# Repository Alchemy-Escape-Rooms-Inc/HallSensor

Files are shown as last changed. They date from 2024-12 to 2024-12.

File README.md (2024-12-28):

# Hall Sensor
Repository dedicated to Alchemy Escape Rooms digital hall sensor

# Folder Structure
## Assembly
Documentation on building

## BOM
.xlsx bom for all parts

## Design
Source code, source models, pcb projects, etc.

## Documentation
User and integration guides, etc.

## Exports
Compiled binaries, printable stl models, etc.

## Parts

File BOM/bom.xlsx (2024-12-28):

Part | Specs | Designation | Mfr Part # | Ordering Reference | Notes
PCB |  |  |  |  | Can be ordered from PCBWay using PCBWay plugin for KiCad, Open Design\PCB\DigitalHallSensor\Panelized\DigitalHallSensorPanelized\Output.kicad_pcb
ALS31300 | 500G Variant | U1 | ALS31300EEJASR-500 | https://www.mouser.com/ProductDetail/250-31300EEJASR500
Capacitor | X7R 0402 0.1uF | C1 | 04026C104KAT2A | https://www.mouser.com/ProductDetail/581-04026C104KAT2A
Header | JST PH 4 Pin Vertical Female Socket | J1, J2 |  | https://www.amazon.com/dp/B0731MZCGF

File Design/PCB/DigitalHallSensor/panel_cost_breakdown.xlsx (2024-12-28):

PanelCount | Total |  | pcb cost per | component cost | total cost per
16 | 80 | 68.55 | 0.171375 | 3 | 3.171375
9 | 45 | 51.03 | 0.2268 | 3 | 3.2268
25 | 125 | 85.8 | 0.13728 | 3 | 3.13728
4 | 20 | 24.88 | 0.2488 | 3 | 3.2488
 | 0 |  | #DIV/0! | 3 | #DIV/0!
 | 0 |  | #DIV/0! | 3 | #DIV/0!
 | 0 |  | #DIV/0! | 3 | #DIV/0!
 | 0 |  | #DIV/0! | 3 | #DIV/0!
 | 0 |  | #DIV/0! | 3 | #DIV/0!
 | 0 |  | #DIV/0! | 3 | #DIV/0!
 | 0 |  | #DIV/0! | 3 | #DIV/0!
 | 0 |  | #DIV/0! | 3 | #DIV/0!

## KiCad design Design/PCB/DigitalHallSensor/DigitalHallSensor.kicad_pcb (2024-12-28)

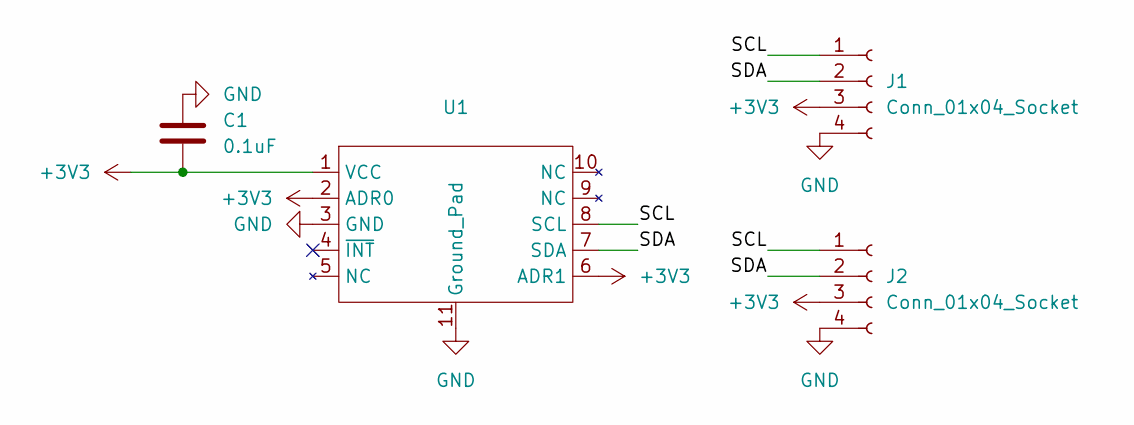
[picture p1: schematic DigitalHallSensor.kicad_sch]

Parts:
C1: 0.1uF; C_0402_1005Metric_Pad0.74x0.62mm_HandSolder
J1, J2: Conn_01x04_Socket; JST_PH_B4B-PH-K_1x04_P2.00mm_Vertical
U1: DFN-10-EJ

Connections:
+3V3: C1.2, J1.3, J2.3, U1.1 (VCC), U1.2 (ADR0), U1.6 (ADR1)
/SCL: J1.1, J2.1, U1.8 (SCL)
/SDA: J1.2, J2.2, U1.7 (SDA)
GND: C1.1, J1.4, J2.4, U1.3 (GND), U1.11 (Ground_Pad)

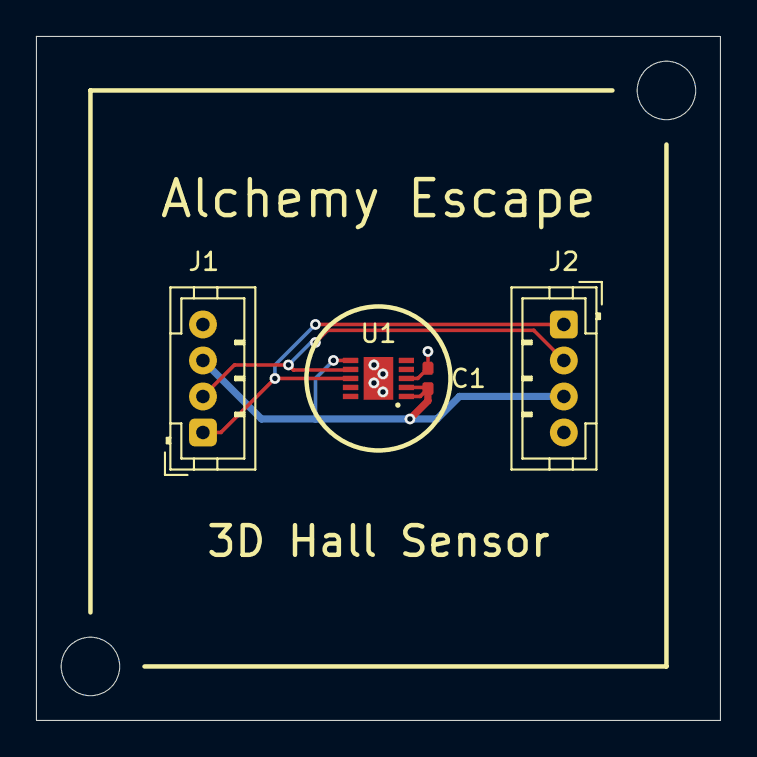
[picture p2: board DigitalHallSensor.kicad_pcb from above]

Board: 2 copper layers, 38.0 x 38.0 mm, 4 parts (0 on the bottom side), 4 nets.

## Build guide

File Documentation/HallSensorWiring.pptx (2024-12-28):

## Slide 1

BAC Wiring (No extenders up to one meter)

Use middle i2c header
And ensure VCCIO jumper is set to pins 2-3 (3.3V)

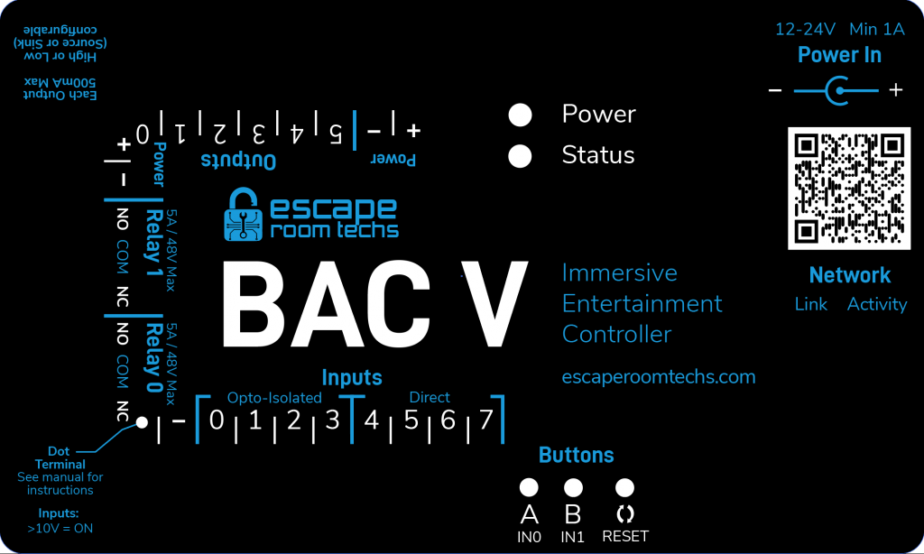
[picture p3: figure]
Escape Room Techs Staff – Escape Room Techs

FX45

I2C

Alchemy Escape
3D Hall Sensor

Alchemy Escape
3D Hall Sensor

Alchemy Escape
3D Hall Sensor

Alchemy Escape
3D Hall Sensor

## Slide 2

BAC Wiring (With extenders)

Use hi drive i2c header
And ensure VCCIO jumper is set to pins 1-2 (5V)

FX45

I2C

FX14-mini

Alchemy Escape
3D Hall Sensor

FX14-mini

FX14-mini

Alchemy Escape
3D Hall Sensor

Diagram incomplete, need hi drive -> ethernet wiring from ERT

Short JST cable

Long ethernet cable

JST Cable

Ethernet

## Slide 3

Microcontroller Wiring (No extenders up to one meter)

2.2K pullup resistor on SCL and SDA

3.3V+

GND

Cable pinout:
Pin 1: SCL
Pin 2: SDA
Pin 3: 3.3V+
Pin 4: Ground

SCL

SDA

Microcontroller

Pin 1 is square pad on hall sensor

Alchemy Escape
3D Hall Sensor

Alchemy Escape
3D Hall Sensor

Alchemy Escape
3D Hall Sensor

Alchemy Escape
3D Hall Sensor

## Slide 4

Microcontroller Wiring (With extenders)

2.2K pullup resistor on SCL and SDA

3.3V+

GND

Cable pinout:
Pin 1: SCL
Pin 2: SDA
Pin 3: 3.3V+
Pin 4: Ground

Microcontroller

SDA

SCL

Pin 1 is square pad on hall sensor

FX14-mini

FX14-mini

Alchemy Escape
3D Hall Sensor

FX14-mini

FX14-mini

Alchemy Escape
3D Hall Sensor

Long ethernet cable

Short JST cable

JST Cable

Ethernet

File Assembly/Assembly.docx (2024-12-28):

# Assembly

1. Tin all surface mount pads
2. Place U1 and hot air into place
3. Place C1 and hot air into place
4. Hand solder J1. The notch should face outward
5. Hand solder J2. The notch should face outward

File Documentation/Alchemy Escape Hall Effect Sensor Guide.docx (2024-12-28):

# Alchemy Escape Hall Effect Sensor

The alchemy escape hall effect sensor is capable of detecting magnet rotation as well as distance. It is based on the Allegro ALS31300 (https://www.allegromicro.com/-/media/files/datasheets/als31300-datasheet.ashx).

# Wiring

The sensors can be chained together using parallel 4 pin JST PH cables. The length of all cables should not exceed ~1 meter. See section on extending I2C for using the sensors at greater distances.

See HallSensorWiring.pdf for detailed wiring diagrams.

# Integration

### Rotational Detection Type

Magnets used for rotational detection need to be diametrically magnetized.

Here (https://www.kjmagnetics.com/proddetail.asp?prod=R834DIA) is a recommended magnet for rotational use.

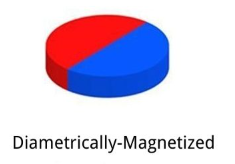
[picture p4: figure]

### Placement Detection Type

Magnets used for placement detection need to be axially magnetized.

The ½” x ½” N52 magnet here (https://shop.escaperoomtechs.com/products/magnets?variant=39931183431886) is a good choice for placement use.

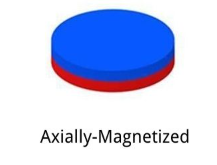
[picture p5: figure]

### Construction

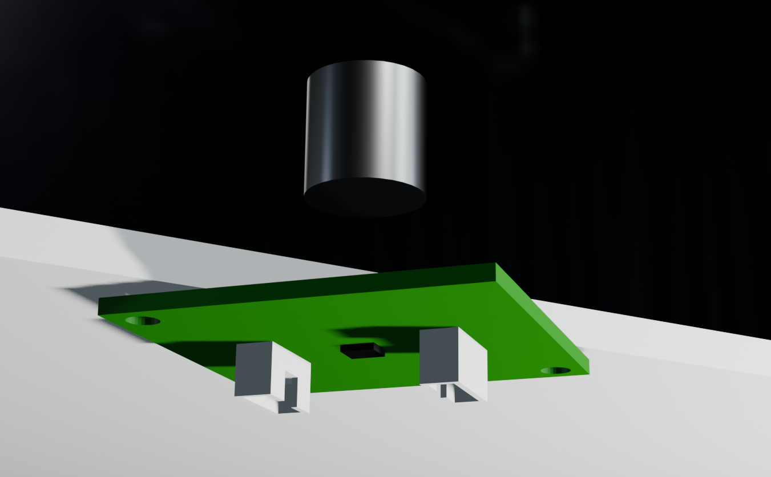
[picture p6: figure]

Sensor should be mounted to a flat surface on the underside. Magnet should be embedded in the prop or on a shaft depending on the detection type.

# Address Programming

Each sensor needs to be programmed with a unique address on the bus. By default, the sensors are programmed with address 0 from the factory. If there are 4 sensors on a bus, you may program them with addresses 1, 2, 3, and 4 for instance. I2C addresses range from 0-127.

BAC Compability Note: the BAC expects these sensors to have addresses 96-111

## Source

The source code (https://github.com/Alchemy-Escape-Rooms-Inc/HallSensor) runs on an ESP32-S3. By setting the old address and new address you can program the sensor. The program will attempt to set the device address on boot.

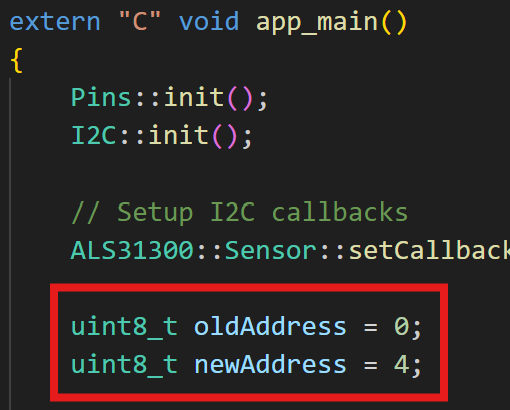
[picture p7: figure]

Here is the output of the example address programming above. First the device is programmed, and then after a power cycle it shows up at address 4.

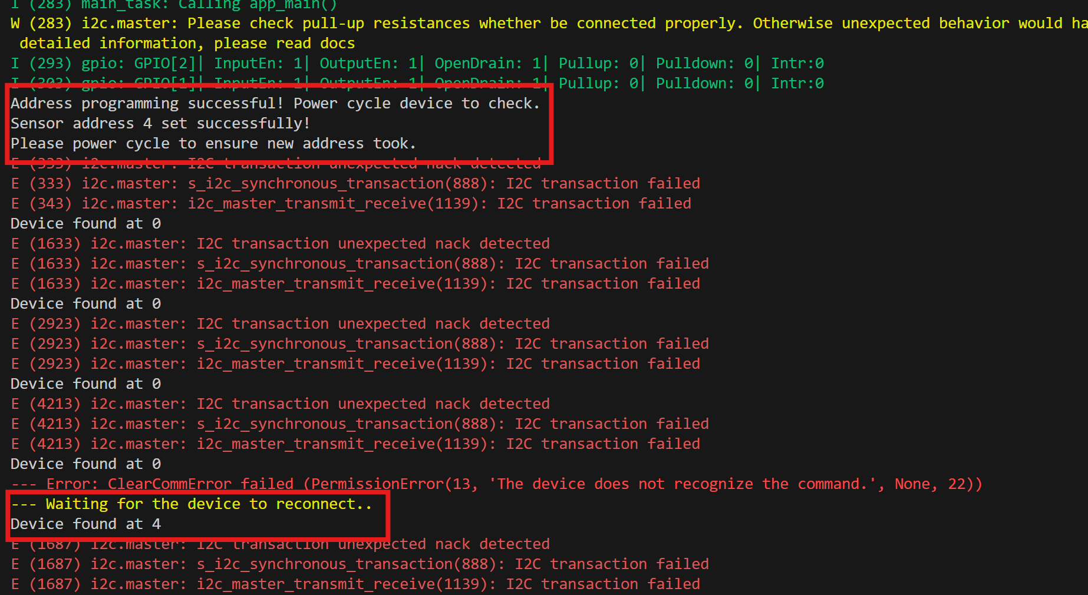
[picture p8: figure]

# Extending I2C

I2C has a max cable distance (end to end with all sensors) of roughly one meter. You can increase the distance by using lower value pullups / dropping transmission speed to get roughly double the distance. If the distances are much larger, you need to use an I2C extender. The FX14-mini (https://shop.escaperoomtechs.com/products/i2c-range-extender-fx14-mini) by Escape Room Techs can accomplish this.

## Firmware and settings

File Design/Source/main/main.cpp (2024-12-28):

#include "freertos/FreeRTOS.h"
#include "freertos/task.h"

#include "allegro/als31300.h"

#include "peripherals/i2c.h"
#include "peripherals/pins.h"

void i2cScan()
{
    // I2C Scanner
    for (int i = 0; i < 128; i++)
    {
        if (I2C::devicePresent(i))
        {
            printf("Device found at %i\n", i);
        }
        vTaskDelay(pdMS_TO_TICKS(10));
    }
}

void setAddress(uint8_t previousAddress, uint8_t newAddress)
{
    ALS31300::Sensor sensor(previousAddress);
    if (sensor.programAddress(newAddress)) printf("Sensor address %i set successfully!\n", newAddress);
    else printf("Sensor address %i failed!\n", newAddress);
}

void processSensor(ALS31300::Sensor& sensor)
{
    if (sensor.update())
    {
        printf("Sensor %i angle: %03d, Depth: %05d\n", sensor.address, sensor.getAngle(), (int) sensor.z);
    }
}

extern "C" void app_main()
{
    Pins::init();
    I2C::init();

    // Setup I2C callbacks
    ALS31300::Sensor::setCallbacks(I2C::registerDevice, I2C::unregisterDevice, I2C::changeAddress, I2C::write, I2C::read);

    uint8_t oldAddress = 0;
    uint8_t newAddress = 4;

    if (I2C::devicePresent(oldAddress))
    {
        // BAC Compatible addresses should be 96-111
        setAddress(oldAddress, newAddress);
        printf("Please power cycle to ensure new address took.\n"); // Power cycle after this
    }
    else
    {
        printf("Sensor address 0 not found, skipping programming!\n");
    }

    ALS31300::Sensor sensor1(1);
    ALS31300::Sensor sensor2(2);
    ALS31300::Sensor sensor3(3);
    ALS31300::Sensor sensor4(4);

    while (1)
    {
        processSensor(sensor1);
        processSensor(sensor2);
        processSensor(sensor3);
        processSensor(sensor4);

        i2cScan();
    }
}

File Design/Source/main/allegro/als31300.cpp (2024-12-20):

#include "als31300.h"
#include "registers.h"

#include <cstdio>
#include <cmath>

namespace ALS31300
{
    Sensor::ReadCallback Sensor::i2cRead = defaultReadCallback;
    Sensor::WriteCallback Sensor::i2cWrite = defaultWriteCallback;
    Sensor::RegisterCallback Sensor::i2cRegister = defaultRegisterCallback;
    Sensor::UnregisterCallback Sensor::i2cUnregister = defaultUnregisterCallback;
    Sensor::ChangeAddressCallback Sensor::i2cChangeAddress = defaultChangeAddressCallback;

    void Sensor::setCallbacks(RegisterCallback registerCallback, UnregisterCallback unregisterCallback, ChangeAddressCallback changeAddressCallback, WriteCallback writeCallback, ReadCallback readCallback)
    {
        i2cWrite = writeCallback;
        i2cRead = readCallback;
        i2cRegister = registerCallback;
        i2cUnregister = unregisterCallback;
        i2cChangeAddress = changeAddressCallback;
    }

    Sensor::Sensor(uint8_t address) : address(address & 0x7F)
    {
        i2cRegister(address);
    }

    Sensor::~Sensor()
    {
        i2cUnregister(address);
    }

    bool Sensor::update()
    {
        uint16_t newX, newY, newZ;

        uint32_t readData;
        if (!read(0x28, readData)) return false;
        Register0x28 reg28{readData};

        newX = reg28.xAxisMsbs << 8;
        newY = reg28.yAxisMsbs << 8;
        newZ = reg28.zAxisMsbs << 8;

        if (!read(0x29, readData)) return false;
        Register0x29 reg29{readData};

        newX |= reg29.xAxisLsbs;
        newY |= reg29.yAxisLsbs;
        newZ |= reg29.zAxisLsbs;

        const float filterIntensity = 32.0f;
        x = (float((int16_t) newX) + x * (filterIntensity - 1)) / filterIntensity;
        y = (float((int16_t) newY) + y * (filterIntensity - 1)) / filterIntensity;
        z = (float((int16_t) newZ) + z * (filterIntensity - 1)) / filterIntensity;

        return true;
    }

    bool Sensor::programAddress(uint8_t newAddress)
    {
        newAddress &= 0x7F;
        
        // Enter Customer Access Mode to enable register writes
        if (!write(customerAccessRegister, customerAccessCode)) return false;

        // Read register
        uint32_t readData;
        if (!read(0x02, readData)) return false;

        // Update address
        Register0x02 registerData = {readData};
        registerData.slaveAddress = newAddress;

        // Write new address
        if (!write(0x02, registerData.raw)) return false;

        printf("Address programming successful! Power cycle device to check.\n");
        
        return true;
    }

    bool Sensor::write(uint8_t reg, uint32_t value)
    {
        uint8_t sendPayload[5] =
        {
            reg,
            uint8_t(value >> 24 & 0xFF),
            uint8_t(value >> 16 & 0xFF),
            uint8_t(value >>  8 & 0xFF),
            uint8_t(value >>  0 & 0xFF)
        };

        return i2cWrite(address, sendPayload, 5);
    }

    bool Sensor::read(uint8_t reg, uint32_t& value)
    {
        uint8_t sendPayload = reg;
        uint8_t receivePayload[4];

        if (!i2cRead(address, &sendPayload, 1, receivePayload, 4)) return false;

        value = receivePayload[0] << 24 |
                receivePayload[1] << 16 |
                receivePayload[2] <<  8 |
                receivePayload[3];

        return true;
    }

    uint16_t Sensor::getAngle()
    {
        // TODO, normalize x and y to skip multiple conversions
        float currentAngle = angleFromXY(x, y);
        float currentX, currentY;
        xyFromAngle(currentAngle, currentX, currentY);

        float avgX, avgY;
        xyFromAngle(avgAngle, avgX, avgY);

        const float filterIntensity = 10.0f;
        avgX = (currentX + avgX * (filterIntensity - 1)) / filterIntensity;
        avgY = (currentY + avgY * (filterIntensity - 1)) / filterIntensity;

        avgAngle = angleFromXY(avgX, avgY);
        
        return avgAngle + 0.5f; // Round angle before casting to uint16_t
    }

    float Sensor::angleFromXY(float x, float y)
    {
        constexpr float PI = float(M_PI);
        constexpr float RAD_TO_DEG (180.0f / PI);

        float angle = atan2f(y, x) * RAD_TO_DEG;
        if (angle < 0) angle += 360.0f;
        
        return angle;
    }

    void Sensor::xyFromAngle(float angle, float& x, float& y)
    {
        constexpr float PI = float(M_PI);
        constexpr float DEG_TO_RAD (PI / 180.0f);

        x = cos(angle * DEG_TO_RAD);
        y = sin(angle * DEG_TO_RAD);
    }
}

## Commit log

2024-12-20 ESP32-S3 project containing integrated hall sensor library
    [partitions.csv]
2024-12-28 enabled i2c scanner, expanded reference to handle multiple sensors, made pin initialization function public
2024-12-28 Supporting documentation and PCB project
    [DigitalHallSensor.kicad_pcb, DigitalHallSensor.kicad_sch, DigitalHallSensorPanelized.kicad_pcb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]
2024-12-28 Added hall sensor wiring document
2025-10-10 Add files via upload
    Added two one click easy to use arduino ide programs to scan and rewrite the hall sensor ids
2026-09-30 ALS31300 address programmer: auto-find the sensor on the bus (0x60-0x67 or factory 0x00), target 0x64
